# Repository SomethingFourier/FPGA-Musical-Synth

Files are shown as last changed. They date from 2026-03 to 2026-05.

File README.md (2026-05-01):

# FPGA-Musical-Synth
A musical synthesizer based on the iCE40 FPGA that outputs I2S audio.

Video demonstration of sine wave synth: https://youtu.be/_ejQGvuSiI8

### 29 April 2026: Key Input PCB design complete!
The PCB for the input module has been completed. Each module represents 1 octave (12 keys). We decided to use shift registers to read key input in parallel and send out that data to the FPGA as serial (PISO). This provides a few advantages over other methods of key input:
1. **Fixed # of FPGA Pins**: We use a fixed number of pins on the FPGA for key input, regardless of how many keys we have.
2. **Daisy Chaining**: Shift registers can be daisy-chained to create a long line of parallel input with just one serial output. To take advantage of this, we designed the modules to daisy chain together, with each additional module in the line giving the user an additional octave.
3. **No Wasted PCBs**: PCB minimum order quantities (often 5) do not produce unused boards because these modules are made to be daisy-chained. If I have to order a minimum of 5 boards, and that's all I want to order, I get 5 octaves for my synth.

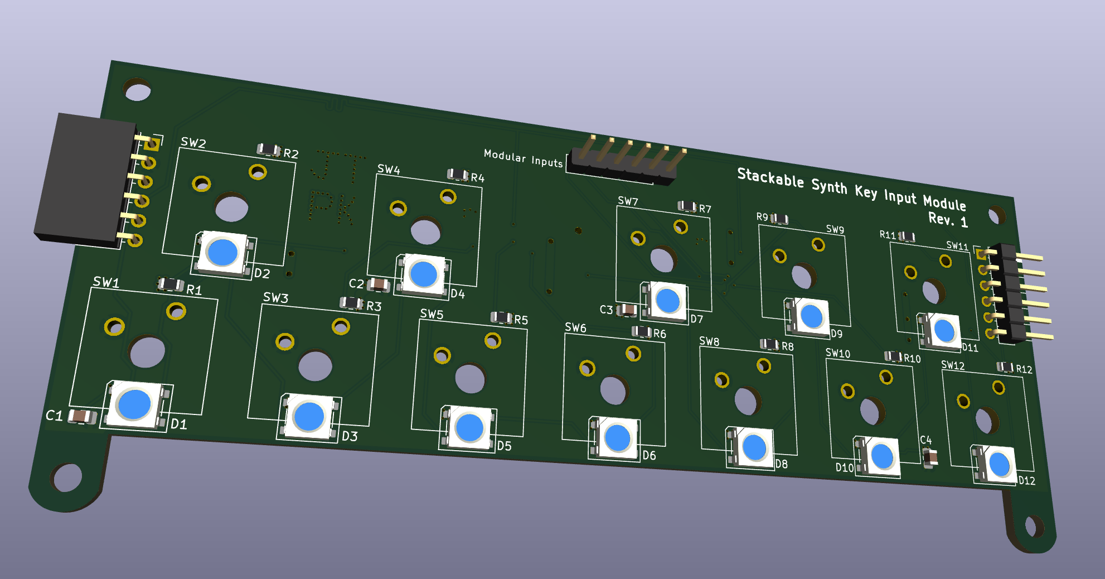
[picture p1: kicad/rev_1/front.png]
top of the key input PCB


> The order for this PCB will be placed within a week or two; I am waiting to order it alongside PCBs for a class I'm currently taking. Because this PCB was designed to daisy-chain duplicates together, it was not designed with a place for an FPGA or the development board; that will be a separate module.

#### Current limitations:
1. FPGA still only supports one key press at a time.
<br>

### 12 March 2026: Numerically Controlled Oscillator (NCO)
Video demonstration of sine wave synth: https://youtu.be/_ejQGvuSiI8

The synth now makes sine waves by the Numerically-Controlled Oscillator (NCO)! This opens the door to make any kind of wave we want just by updating the ROMs. Additionally, a multi-clock cycle multiplication algorithm has been implemented to save space on the FPGA and take advantage of the 512 master clock cycles between one sample and the next.

#### Current limitations:
1. Only supports one key press at a time.
<br>

### 2 Feb 2026: Square Wave Synthesizer
Video demonstration of square wave synth: https://youtu.be/o0nXdgJRZlI

The wave_period_selector method of synthesis used is described by this process:
> wave_period_selector sends the half-period of the frequency (musical note) associated with the key pressed to i2s_transmitter. i2s_transmitter sends a square wave via I2S that oscillates every half-period (the one sent to it by wave_period_selector) to an I2S DAC. This generates a square wave at the desired frequency.

The square wave synth only supports one key press at a time. If multiple keys are pressed, the key that gets checked first in wave_period_selector is the note that gets played. Further, due to the nature of this synthesis, this only supports square waves.
<br>

### Hardware:
1. pico2-ice development board
2. Adafruit I2S 3W Class D Amplifier

### Software Tools:
##### 1. RTL Synthesis:
> OSS-CAD-SUITE is being used for iCE40 synthesis, Place-and-Route, as well as packing.
##### 2. Simulation:
> Icarus Verilog (iverilog) is being used for test bench simulation and other debugging. Verilator may replace icarus if it is decided that it is superior for testbenching this project's verilog modules.
##### 3. HDL:
> The FPGA was programmed in SystemVerilog.

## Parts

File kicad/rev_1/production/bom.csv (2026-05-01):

Designator | Footprint | Quantity | Value | LCSC Part #
C1, C2, C3, C4, C5, C6 | 0805 | 6 | 0.1 µF
D1, D10, D11, D12, D2, D3, D4, D5, D6, D7, D8, D9 | LED_WS2812B_PLCC4_5.0x5.0mm_P3.2mm | 12 | WS2812B
J1 | PinSocket_1x06_P2.54mm_Horizontal | 1 | Connect to Upper Module/Motherboard
J2 | PinHeader_1x06_P2.54mm_Horizontal | 1 | Connect to Lower Module
J3 | PinHeader_1x06_P2.54mm_Vertical | 1 | Modular Inputs
R1, R10, R11, R12, R2, R3, R4, R5, R6, R7, R8, R9 | 0805 | 12 | 11k
SW1, SW10, SW11, SW12, SW2, SW3, SW4, SW5, SW6, SW7, SW8, SW9 | SW_Cherry_MX_1.00u_Plate | 12 | SW_Push
U1, U2 | SOIC127P600X175-16N | 2 | 74HC165

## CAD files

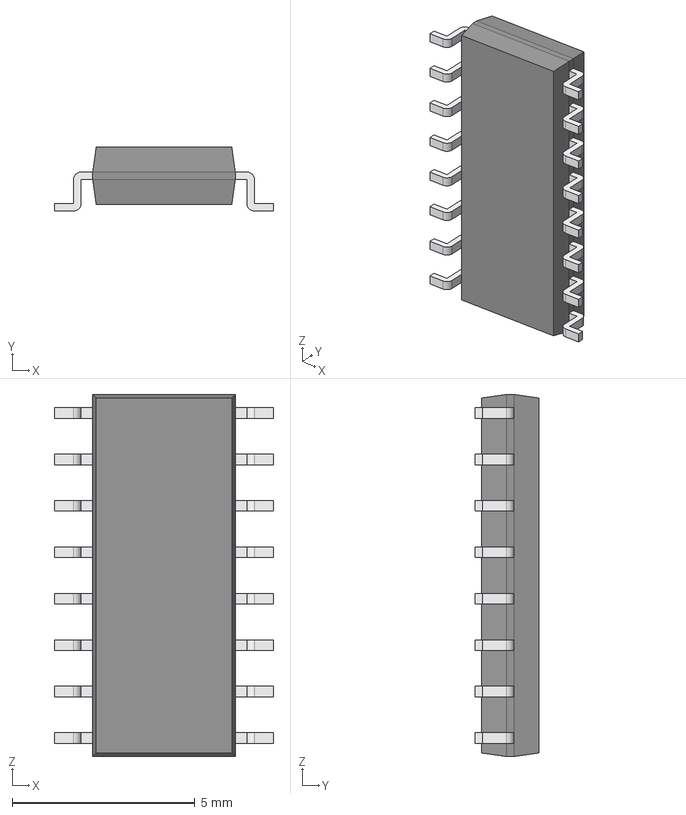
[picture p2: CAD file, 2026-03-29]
kicad/rev_1/Local Libraries/74HC165D_653/74HC165D_653.step
6.00 x 1.75 x 9.90 mm
Body001 (Mirror #1) x 8
XY-plane x 12
X-axis x 12

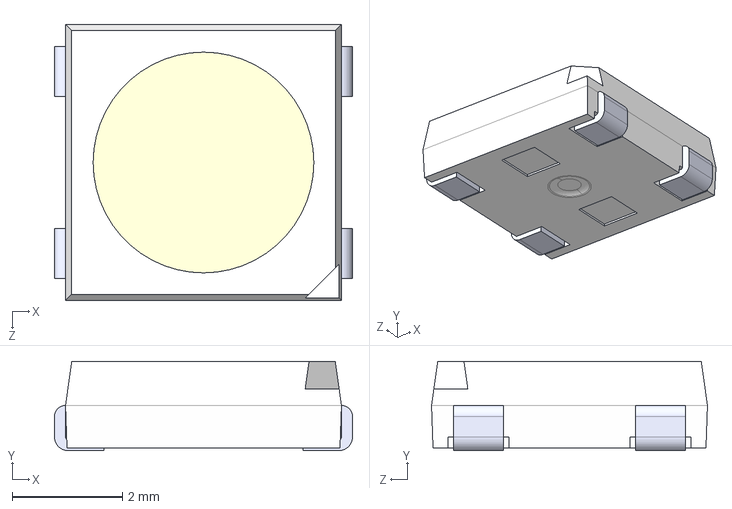
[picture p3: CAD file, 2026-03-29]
kicad/rev_1/Local Libraries/WS2812B/WS2812B.step
5.40 x 1.62 x 5.00 mm

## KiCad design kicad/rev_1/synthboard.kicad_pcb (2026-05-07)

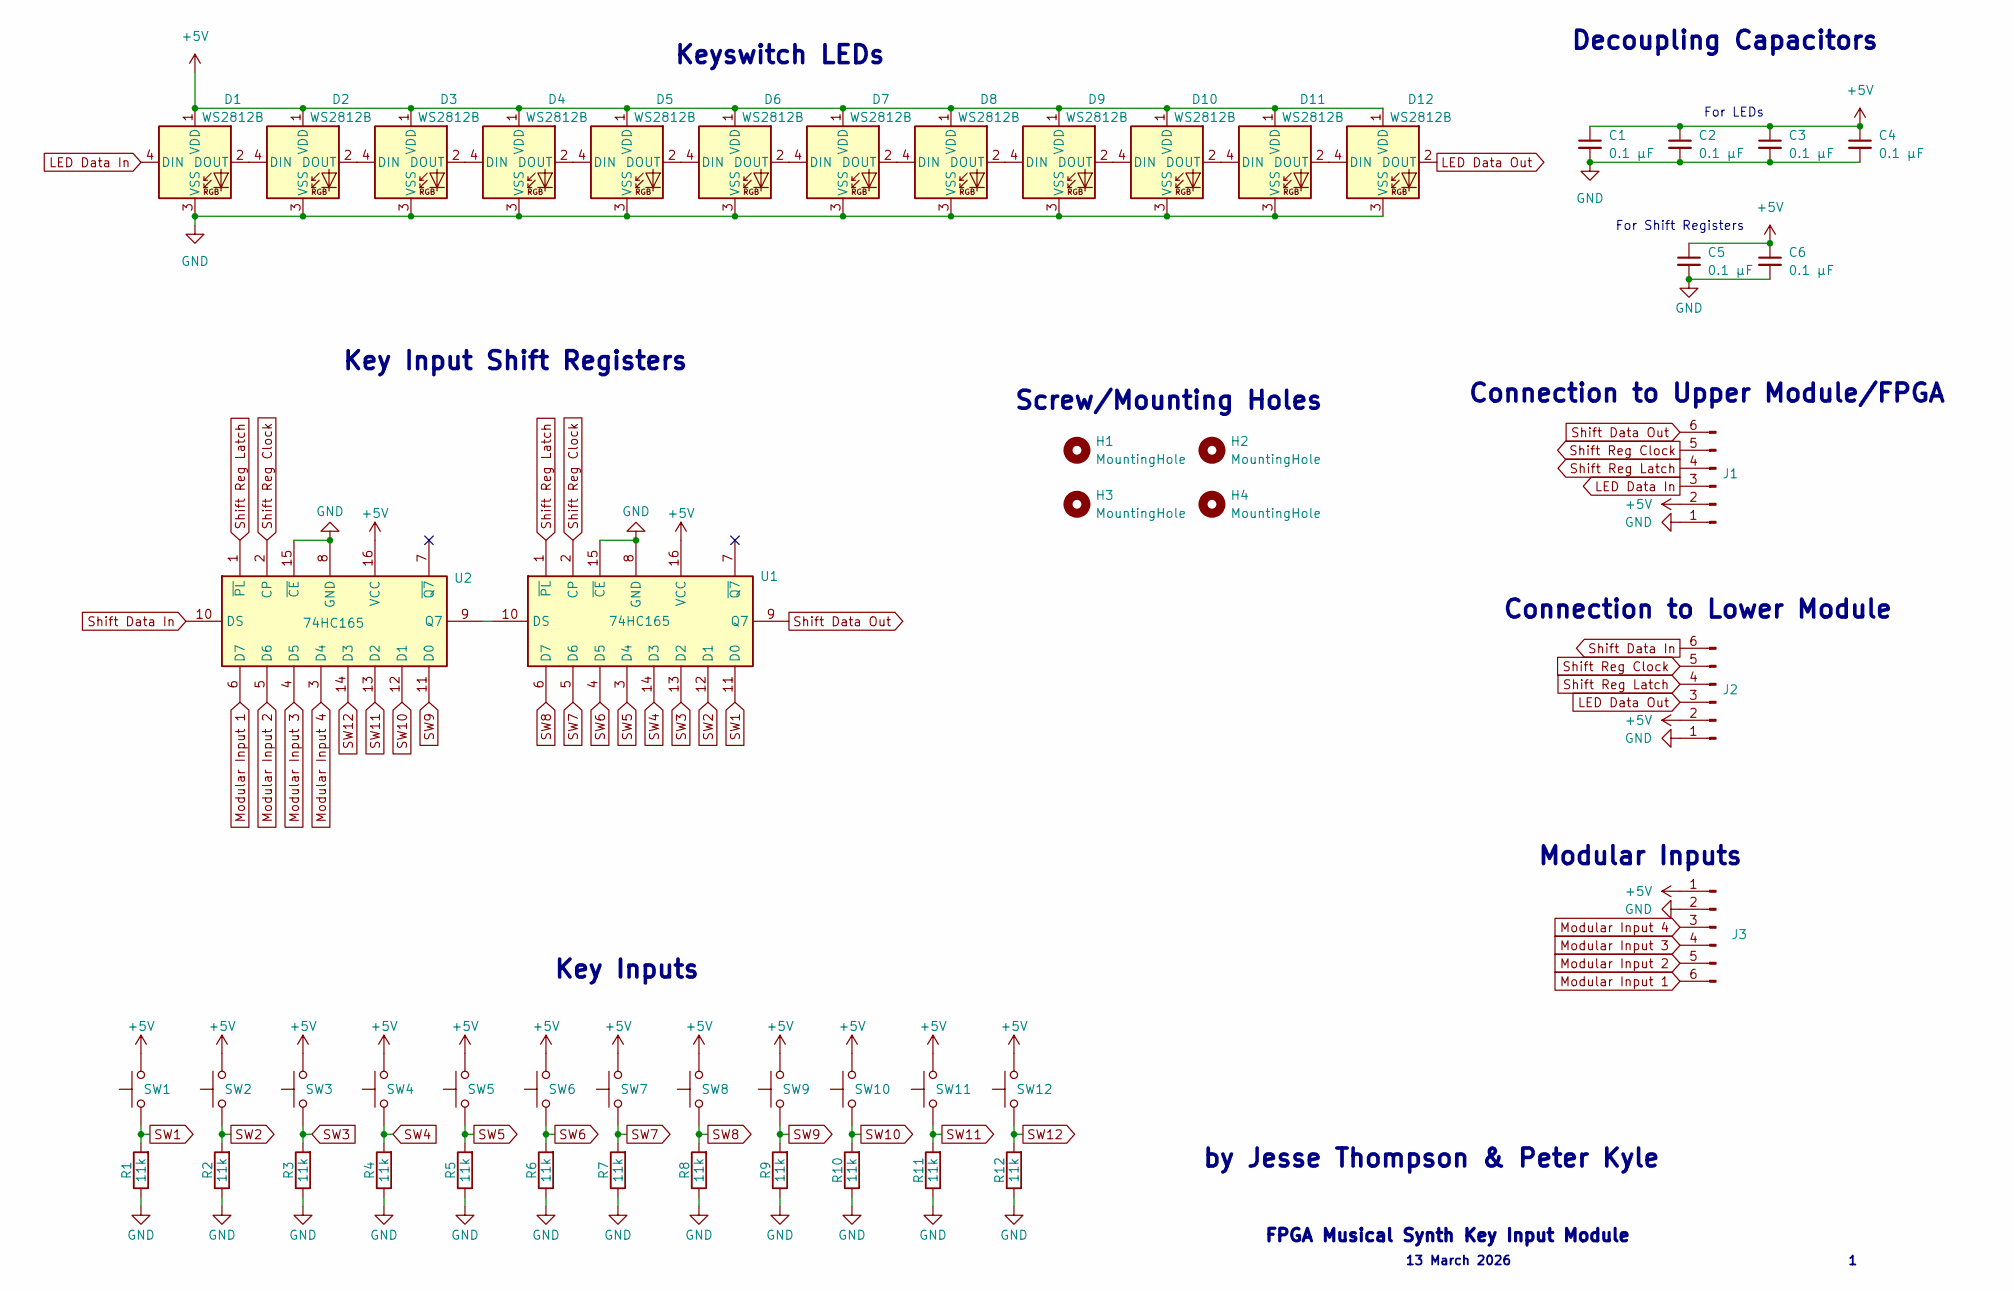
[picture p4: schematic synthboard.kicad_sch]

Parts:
C1, C2, C3, C4, C5, C6: 0.1 µF; C_0805_2012Metric
D1, D2, D3, D4, D5, D6, D7, D8, D9, D10, D11, D12: WS2812B; LED_WS2812B_PLCC4_5.0x5.0mm_P3.2mm
H1, H2, H3, H4: MountingHole; MountingHole_3.2mm_M3
J1: Connect to Upper Module/Motherboard; PinSocket_1x06_P2.54mm_Horizontal
J2: Connect to Lower Module; PinHeader_1x06_P2.54mm_Horizontal
J3: Modular Inputs; PinHeader_1x06_P2.54mm_Vertical
R1, R2, R3, R4, R5, R6, R7, R8, R9, R10, R11, R12: 11k; R_0805_2012Metric
SW1, SW2, SW3, SW4, SW5, SW6, SW7, SW8, SW9, SW10, SW11, SW12: SW_Push; SW_Cherry_MX_1.00u_Plate
U1, U2: 74HC165; SOIC127P600X175-16N

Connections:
+5V: C1.1, C2.1, C3.1, C4.1, C5.1, C6.1, D1.1 (VDD), D2.1 (VDD), D3.1 (VDD), D4.1 (VDD), D5.1 (VDD), D6.1 (VDD), D7.1 (VDD), D8.1 (VDD), D9.1 (VDD), D10.1 (VDD), D11.1 (VDD), D12.1 (VDD), J1.2, J2.2, J3.1, SW1.2, SW2.2, SW3.2, SW4.2, SW5.2, SW6.2, SW7.2, SW8.2, SW9.2, SW10.2, SW11.2, SW12.2, U1.16 (VCC), U2.16 (VCC)
GND: C1.2, C2.2, C3.2, C4.2, C5.2, C6.2, D1.3 (VSS), D2.3 (VSS), D3.3 (VSS), D4.3 (VSS), D5.3 (VSS), D6.3 (VSS), D7.3 (VSS), D8.3 (VSS), D9.3 (VSS), D10.3 (VSS), D11.3 (VSS), D12.3 (VSS), J1.1, J2.1, J3.2, R1.1, R2.1, R3.1, R4.1, R5.1, R6.1, R7.1, R8.1, R9.1, R10.1, R11.1, R12.1, U1.8 (GND), U1.15 (~CE), U2.8 (GND), U2.15 (~CE)
LED Data In: D1.4 (DIN), J1.3
LED Data Out: D12.2 (DOUT), J2.3
Modular Input 1: J3.6, U2.6 (D7)
Modular Input 2: J3.5, U2.5 (D6)
Modular Input 3: J3.4, U2.4 (D5)
Modular Input 4: J3.3, U2.3 (D4)
unnamed: D1.2 (DOUT), D2.4 (DIN)
unnamed: D2.2 (DOUT), D3.4 (DIN)
unnamed: D3.2 (DOUT), D4.4 (DIN)
unnamed: D4.2 (DOUT), D5.4 (DIN)
unnamed: D5.2 (DOUT), D6.4 (DIN)
unnamed: D6.2 (DOUT), D7.4 (DIN)
unnamed: D7.2 (DOUT), D8.4 (DIN)
unnamed: D8.2 (DOUT), D9.4 (DIN)
unnamed: D9.2 (DOUT), D10.4 (DIN)
unnamed: D10.2 (DOUT), D11.4 (DIN)
unnamed: D11.2 (DOUT), D12.4 (DIN)
unnamed: U1.10 (DS), U2.9 (Q7)
SW1: R1.2, SW1.1, U1.11 (D0)
SW2: R2.2, SW2.1, U1.12 (D1)
SW3: R3.2, SW3.1, U1.13 (D2)
SW4: R4.2, SW4.1, U1.14 (D3)
SW5: R5.2, SW5.1, U1.3 (D4)
SW6: R6.2, SW6.1, U1.4 (D5)
SW7: R7.2, SW7.1, U1.5 (D6)
SW8: R8.2, SW8.1, U1.6 (D7)
SW9: R9.2, SW9.1, U2.11 (D0)
SW10: R10.2, SW10.1, U2.12 (D1)
SW11: R11.2, SW11.1, U2.13 (D2)
SW12: R12.2, SW12.1, U2.14 (D3)
Shift Data In: J2.6, U2.10 (DS)
Shift Data Out: J1.6, U1.9 (Q7)
Shift Reg Clock: J1.5, J2.5, U1.2 (CP), U2.2 (CP)
Shift Reg Latch: J1.4, J2.4, U1.1 (~PL), U2.1 (~PL)

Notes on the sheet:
Key Inputs
by Jesse Thompson & Peter Kyle
For Shift Registers
13 March 2026
Keyswitch LEDs
Decoupling Capacitors
Connection to Upper Module/FPGA
Key Input Shift Registers
FPGA Musical Synth Key Input Module
Connection to Lower Module
Modular Inputs
For LEDs
Screw/Mounting Holes

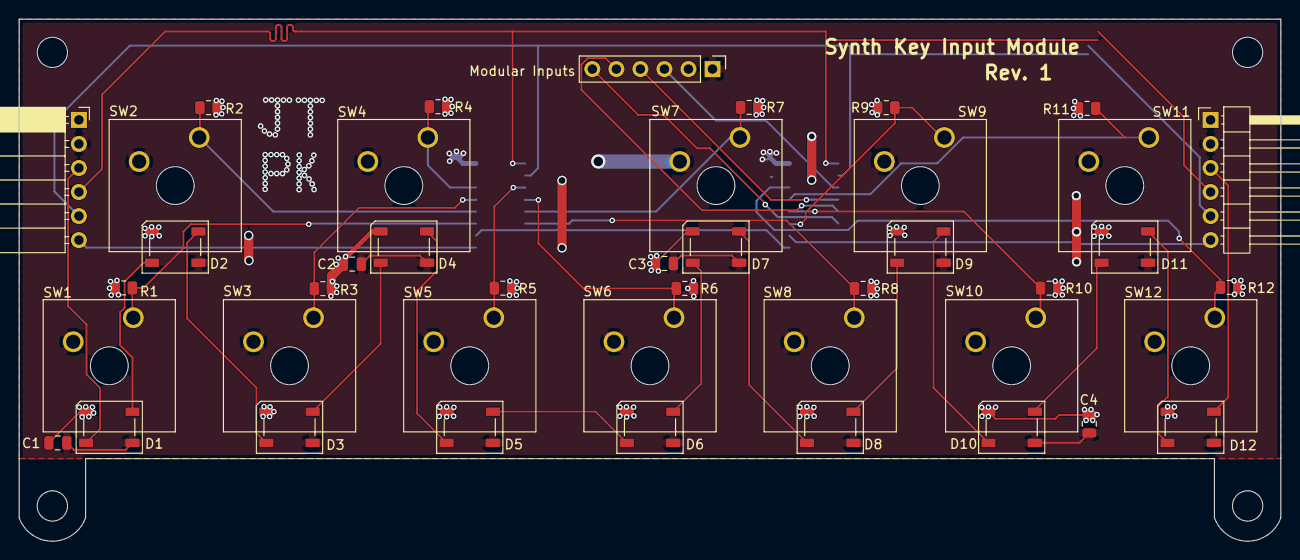
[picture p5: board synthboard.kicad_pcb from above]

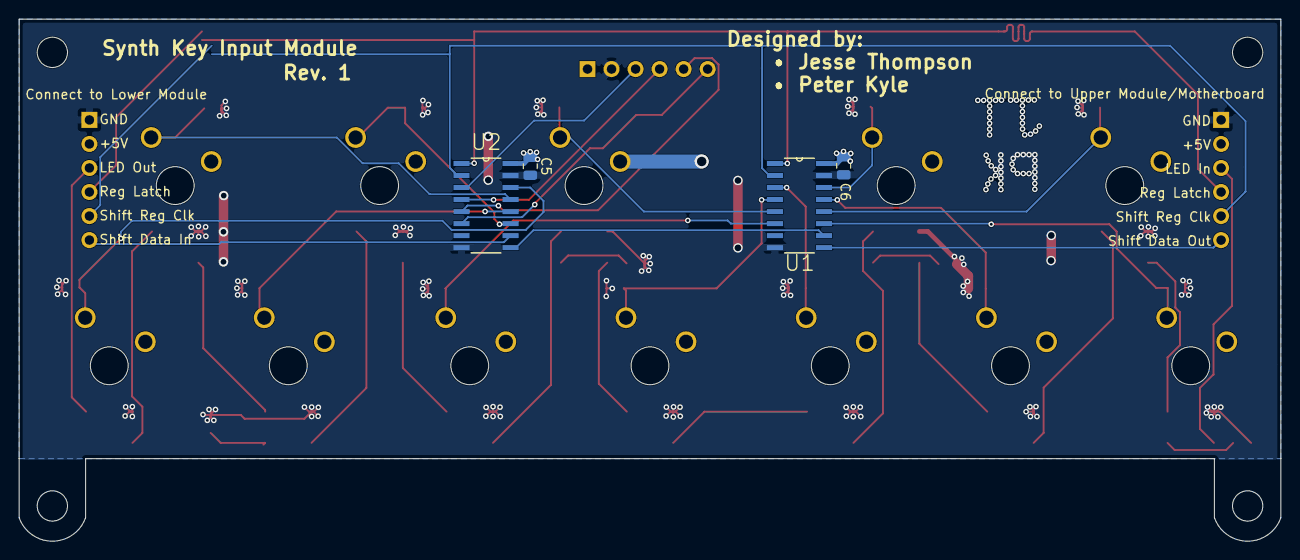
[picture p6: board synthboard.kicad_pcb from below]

Board: 2 copper layers, 133.3 x 55.2 mm, 51 parts (4 on the bottom side), 36 nets.

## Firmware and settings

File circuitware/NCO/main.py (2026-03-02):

from machine import Pin
import time
import ice

LED_R = Pin(1, Pin.OUT)
LED_G = Pin(0, Pin.OUT)
LED_B = Pin(9, Pin.OUT)

LED_R.value(1)
LED_G.value(1)
LED_B.value(1)

file = open("synth.bin", "br")
flash = ice.flash(miso=Pin(4), mosi=Pin(7), sck=Pin(6), cs=Pin(5))
flash.erase(4096) # Optional
flash.write(file)
# Optional
fpga = ice.fpga(cdone=Pin(40), clock=Pin(21), creset=Pin(31), cram_cs=Pin(5), cram_mosi=Pin(4), cram_sck=Pin(6), frequency=24.576)
fpga.start()

FPGA_RESET = Pin(30 , Pin.OUT)

FPGA_RESET.value(0)
time.sleep(1)
FPGA_RESET.value(1)

'''
LED_R.value(0)
LED_G.value(0)
LED_B.value(0)
'''

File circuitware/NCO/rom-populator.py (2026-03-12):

import math
import matplotlib.pyplot as plt

PERIODIC = True

waveform_rom = []

for i in range(32):
    waveform_rom.append(0.5*math.sin(2*math.pi*i/32)*(2**15-1))

waveform_slope_rom = []


for i in range(32):
    if i == 31:
        if PERIODIC:
            waveform_slope_rom.append((waveform_rom[0]-waveform_rom[i])*4)
        else:
            # If not defined as periodic (we want a discontinuity) then use the second to last slope as the last slope.
            waveform_slope_rom.append(waveform_slope_rom[30])
    else:
        waveform_slope_rom.append((waveform_rom[i+1]-waveform_rom[i])*4)

plt.scatter(range(32), waveform_rom, color='blue', label='waveform')
plt.scatter(range(32), waveform_slope_rom, color='red', label='slope*4')

plt.legend()

plt.show()

print(waveform_rom)

print(waveform_slope_rom)

print("---")

print("@00 ", end='')
for sample in waveform_rom:
    if sample < 0:
        print(f"{(1<<16)+int(sample):04X}")
    else:
        print(f"{int(sample):04X}")



print("---")

print("@00 ", end='')
for sample in waveform_slope_rom:
    if sample < 0:
        print(f"{(1<<16)+int(sample):04X}")
    else:
        print(f"{int(sample):04X}")

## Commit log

2026-03-03 Update nco.sv
    Added a multitude of comments and removed a couple things left from debugging.
2026-03-05 Partially Functional Booth's Algorithm Implementation
    It's halfway there 😐
2026-03-11 Update bouncy_key13 pin assignment
2026-03-11 Fixed 13th key frequency
    [rom-populator.py]
2026-03-29 PCB development for input board started
    Not done. Need to make a GND and +3.3V layer
    [74HC165D_653.step, WS2812B.step, synthboard.kicad_pcb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]
2026-03-29 first draft PCB design done
    Will look for errors with fresh eyes later.
    [synthboard.kicad_pcb]
2026-03-30 Added 2 layer board
    4 layer board has been separated into separate folder.
    The 2 layer board passes DRC.
    Need to potentially revise schematic. I think the shift registers may not be talking to each other with just one communicating with the data in/out pins on the board.
    [74HC165D_653.step, WS2812B.step, synthboard.kicad_pcb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]
2026-03-30 2 layer board rev 1 tentatively finished
    Hoping for a design review
    [synthboard.kicad_pcb, synthboard.kicad_sch]
2026-04-01 2 layer board edits
    [74HC165D_653.step, WS2812B.step, synthboard.kicad_pcb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]
2026-04-29 Updated README, finished key input module PCB
    README now follows a dated update structure to make new content additions easier.
    PCB Design for the key input module has been completed. Images from KiCAD's 3D viewer have been generated for sharing.
    [74HC165D_653.step, WS2812B.step, synthboard.kicad_pcb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]
2026-05-01 Added Text to PCB & Updated README
    Added informational text to PCB, including designer names, board name, and revision number.
    Improved quality of the PCB Image by screenshotting the KiCad 3D viewer instead of using the native export function.
    [bom.csv, designators.csv, positions.csv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]
2026-05-07 PCB updates
    edited silkscreen and generated final production files for JLCPCB
    [synthboard.kicad_pcb]
